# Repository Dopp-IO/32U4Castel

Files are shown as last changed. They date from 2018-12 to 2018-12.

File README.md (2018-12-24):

# 32U4Castel
Tiny castellated 32U4 module

Part	Value	      Package  
C1	  0.1uF		    0603-CAP  
C2	  22pF		    0603-CAP  
C3	  0.1uF		    0603-CAP  
C4	  22pF		    0603-CAP  
C5	  1uF		      0603-CAP  
C6	  1uF		      0603-CAP  
C7	  1uF		      0603-CAP  
C8	  1uF		      0603-CAP  
C9	  1uF		      0603-CAP  
C10	  1uF		      0603-CAP  
LED1	Red		      LED-0603  
R1	  10K		      0603-RES  
R2	  22		      0603-RES  
R3	  22		      0603-RES  
R4	  1K		      0603-RES  
U1	  ATMEGA32U4	QFN-44  
Y1	  16MHz		    CRYSTAL-SMD-5X3

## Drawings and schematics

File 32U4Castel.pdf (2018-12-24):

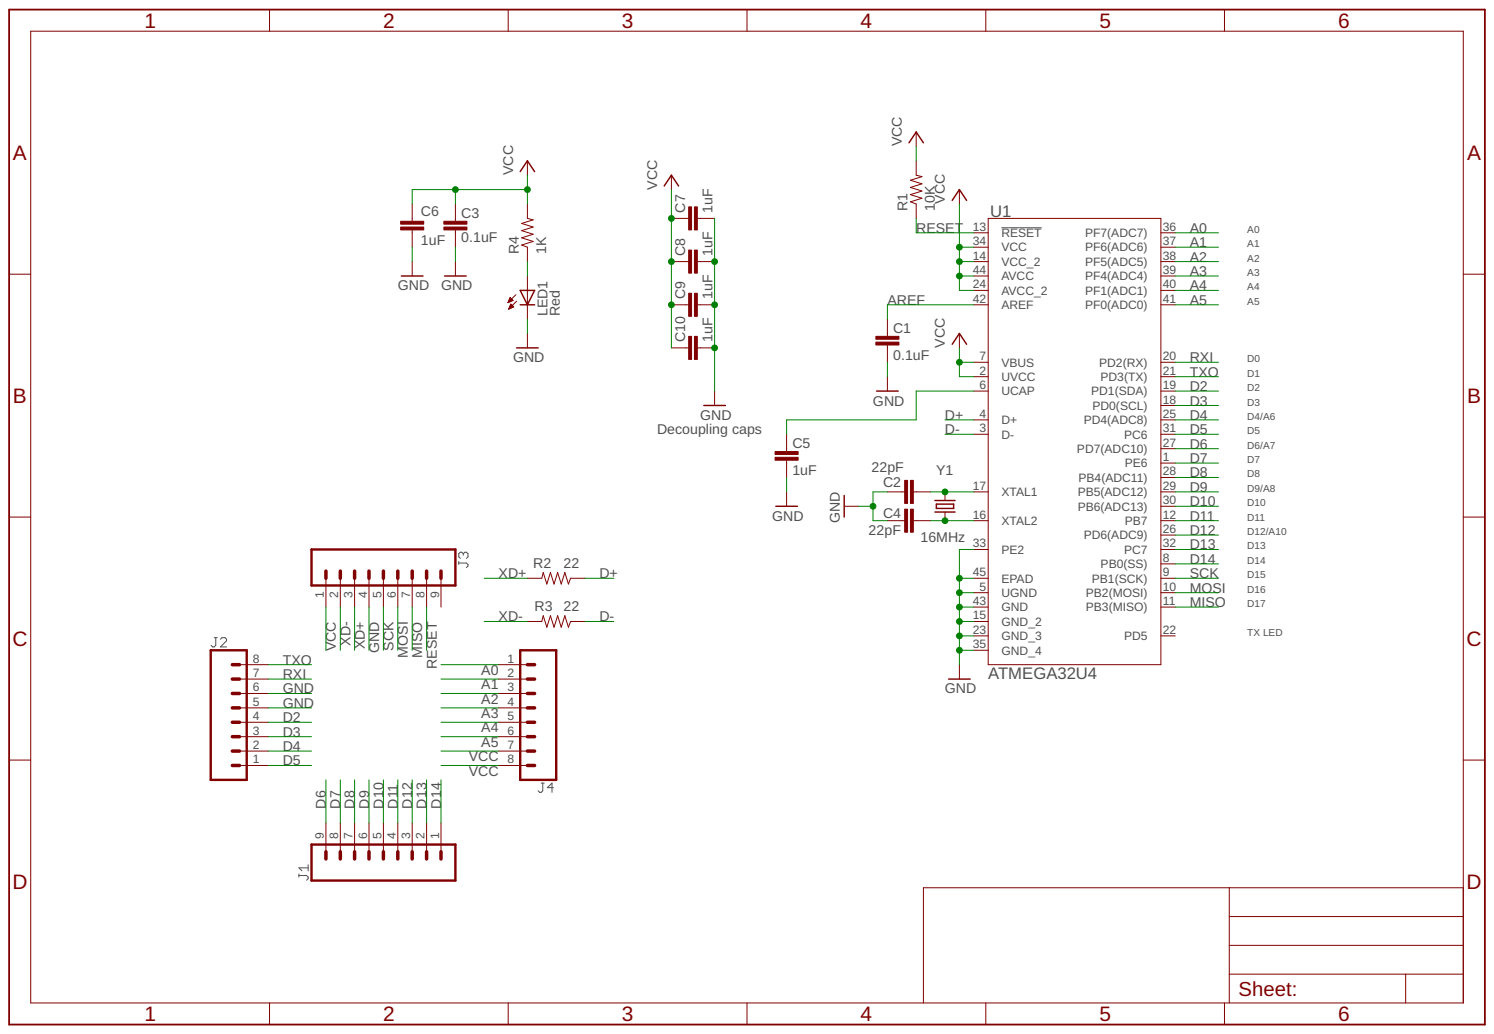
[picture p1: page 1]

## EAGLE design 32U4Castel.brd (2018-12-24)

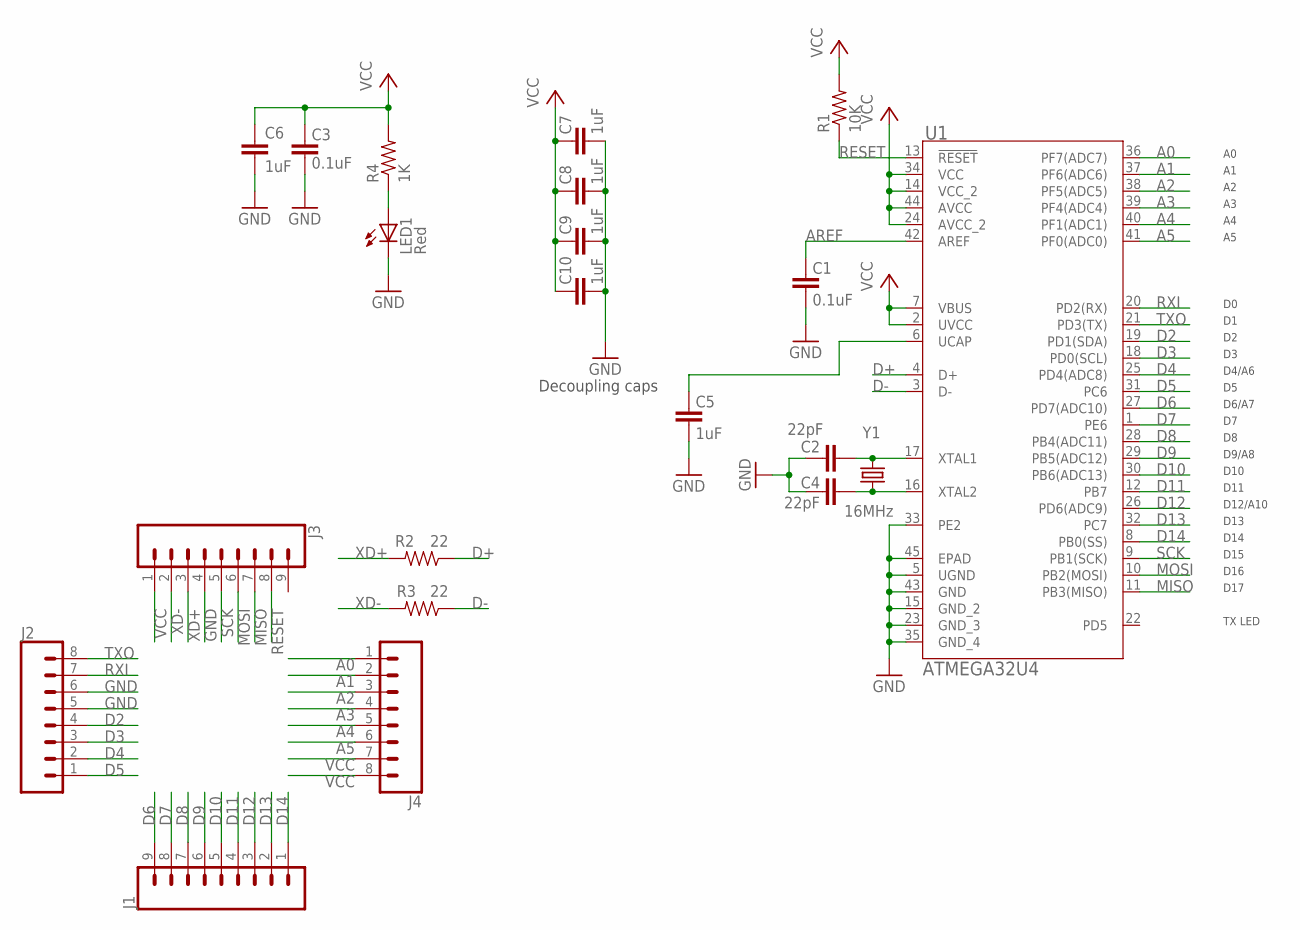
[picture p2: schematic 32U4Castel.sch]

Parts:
C1, C3: 0.1uF; 0603-CAP
C2, C4: 22pF; 0603-CAP
C5, C6, C7, C8, C9, C10: 1uF; 0603-CAP
J1, J3: CONN_09NO_SILK; 1X09_NO_SILK
J2, J4: CONN_08NO_SILK_FEMALE_PTH; 1X08_NO_SILK
LED1: Red; LED-0603
R1: 10K; 0603-RES
R2, R3: 22; 0603-RES
R4: 1K; 0603-RES
U1: ATMEGA32U4-MU; 44PW
Y1: 16MHz; CRYSTAL-SMD-5X3

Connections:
A0: J4.1, U1.36 (PF7(ADC7))
A1: J4.2, U1.37 (PF6(ADC6))
A2: J4.3, U1.38 (PF5(ADC5))
A3: J4.4, U1.39 (PF4(ADC4))
A4: J4.5, U1.40 (PF1(ADC1))
A5: J4.6, U1.41 (PF0(ADC0))
AREF: C1.2, U1.42 (AREF)
D2: J2.4, U1.19 (PD1(SDA))
D3: J2.3, U1.18 (PD0(SCL))
D4: J2.2, U1.25 (PD4(ADC8))
D5: J2.1, U1.31 (PC6)
D6: J1.9, U1.27 (PD7(ADC10))
D7: J1.8, U1.1 (PE6)
D8: J1.7, U1.28 (PB4(ADC11))
D9: J1.6, U1.29 (PB5(ADC12))
D10: J1.5, U1.30 (PB6(ADC13))
D11: J1.4, U1.12 (PB7)
D12: J1.3, U1.26 (PD6(ADC9))
D13: J1.2, U1.32 (PC7)
D14: J1.1, U1.8 (PB0(SS))
D+: R2.1, U1.4 (D+)
D-: R3.1, U1.3 (D-)
GND: C1.1, C2.2, C3.1, C4.2, C5.1, C6.2, C7.1, C8.1, C9.1, C10.1, J2.5, J2.6, J3.4, LED1.C, U1.5 (UGND), U1.15 (GND_2), U1.23 (GND_3), U1.33 (PE2), U1.35 (GND_4), U1.43 (GND), U1.45 (EPAD)
LED: LED1.A, R4.1
MISO: J3.7, U1.11 (PB3(MISO))
MOSI: J3.6, U1.10 (PB2(MOSI))
RESET: J3.8, R1.1, U1.13 (!RESET)
RXI: J2.7, U1.20 (PD2(RX))
SCK: J3.5, U1.9 (PB1(SCK))
TXO: J2.8, U1.21 (PD3(TX))
UCAP: C5.2, U1.6 (UCAP)
VCC: C3.2, C6.1, C7.2, C8.2, C9.2, C10.2, J3.1, J4.7, J4.8, R1.2, R4.2, U1.2 (UVCC), U1.7 (VBUS), U1.14 (VCC_2), U1.24 (AVCC_2), U1.34 (VCC), U1.44 (AVCC)
X1: C2.1, U1.17 (XTAL1), Y1.3 (2)
X2: C4.1, U1.16 (XTAL2), Y1.1
XD+: J3.3, R2.2
XD-: J3.2, R3.2

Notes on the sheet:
Decoupling caps

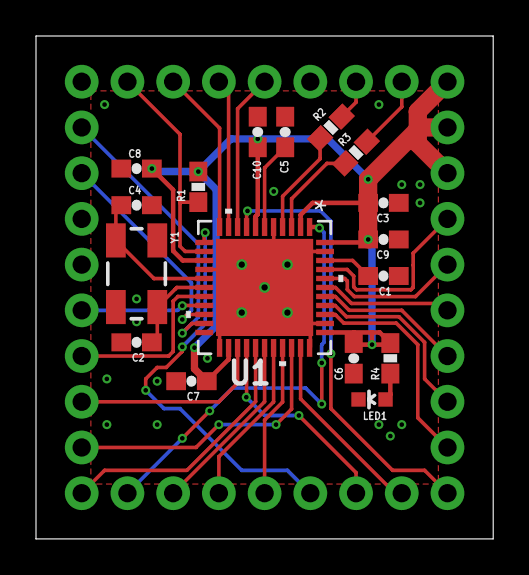
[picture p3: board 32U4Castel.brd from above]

Board: 2 copper layers, 25.4 x 27.9 mm, 21 parts (0 on the bottom side), 36 nets.

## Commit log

2018-08-10 Added eagle and gerber files
    [32U4Castel.brd, 32U4Castel.sch]
2018-08-10 Added BOM
2018-08-11 Added schematic PDF
2018-08-15 Added pad, complete re-route
    Fabrication was difficult because of non-ground vias where 32U4 wanted a pad. Added pad, rerouted everything. Improved silkscreen.
    [32U4Castel.brd, 32U4Castel.sch]
2018-12-24 Updated 32U4Castel
    Fixed mis-mapped SS pin and improved grounding.
    [32U4Castel.brd, 32U4Castel.sch]

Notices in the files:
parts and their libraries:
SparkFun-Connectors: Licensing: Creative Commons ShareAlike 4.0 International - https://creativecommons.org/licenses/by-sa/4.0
